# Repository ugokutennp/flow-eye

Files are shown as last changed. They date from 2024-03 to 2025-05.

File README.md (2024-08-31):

# flow-eye
IR Illuminator and Camera Mount for Valve Index DIY Eye Tracker

## Prototype
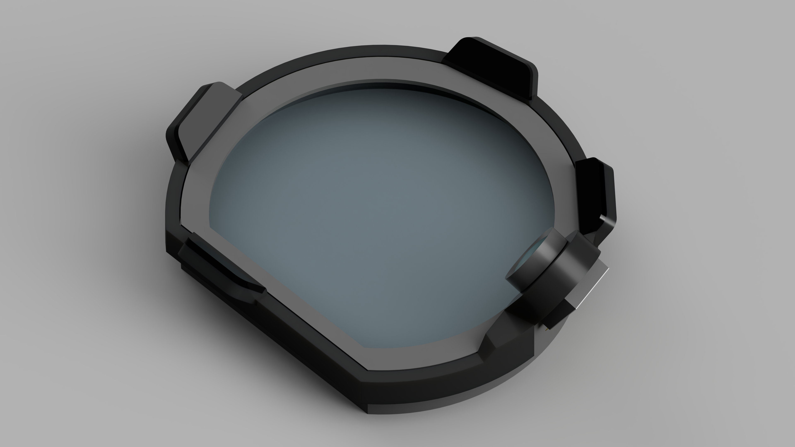
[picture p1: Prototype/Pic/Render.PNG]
Render

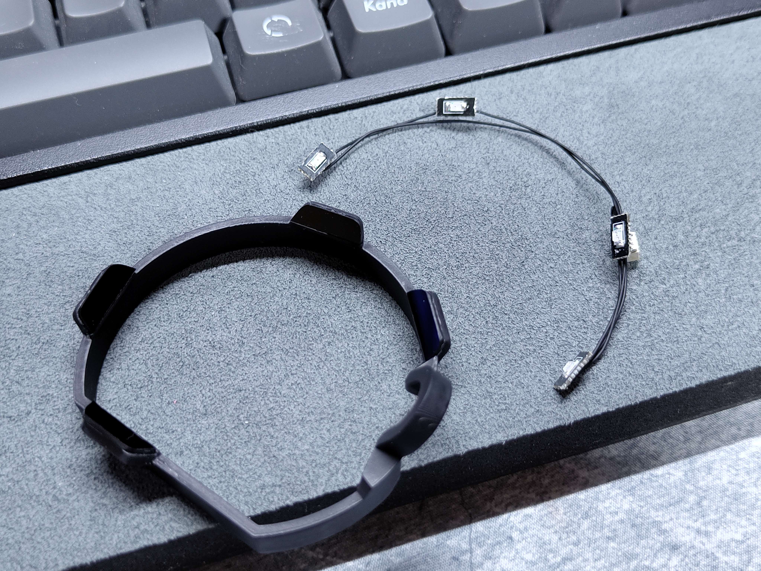
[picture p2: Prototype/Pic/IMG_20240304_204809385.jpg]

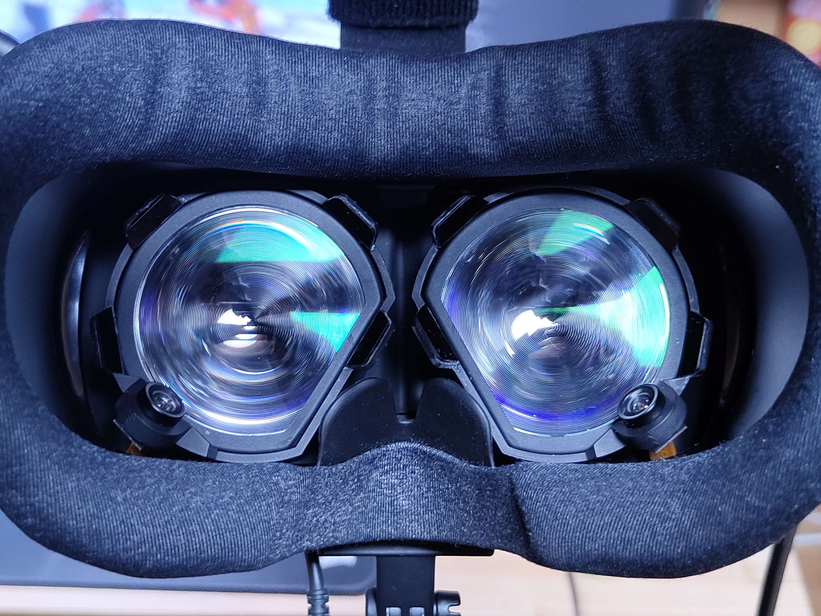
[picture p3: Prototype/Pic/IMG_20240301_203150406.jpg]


### Note
 - Designed for OV2640-160°.
 - A rubber ring is used to mount the camera.
 - The part in front of the LED is a visible light filter (acrylic that passes only infrared light). It is attached for appearance.

## Rev1.1
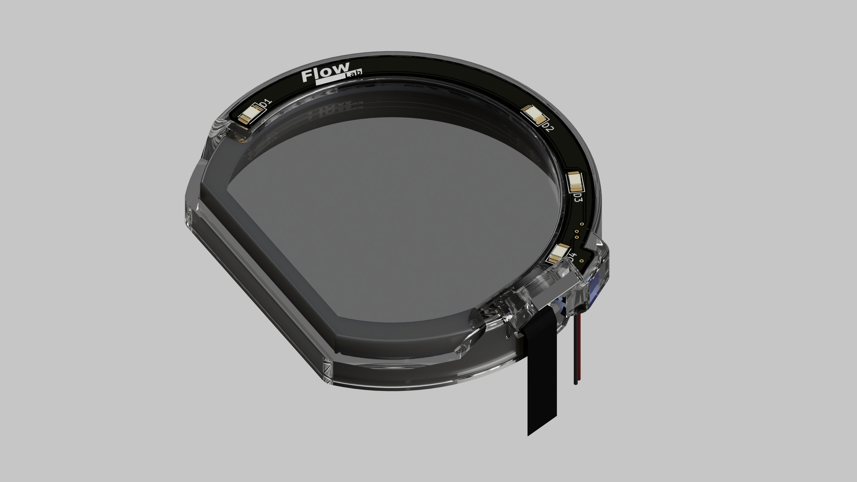
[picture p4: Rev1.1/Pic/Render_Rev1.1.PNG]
Render

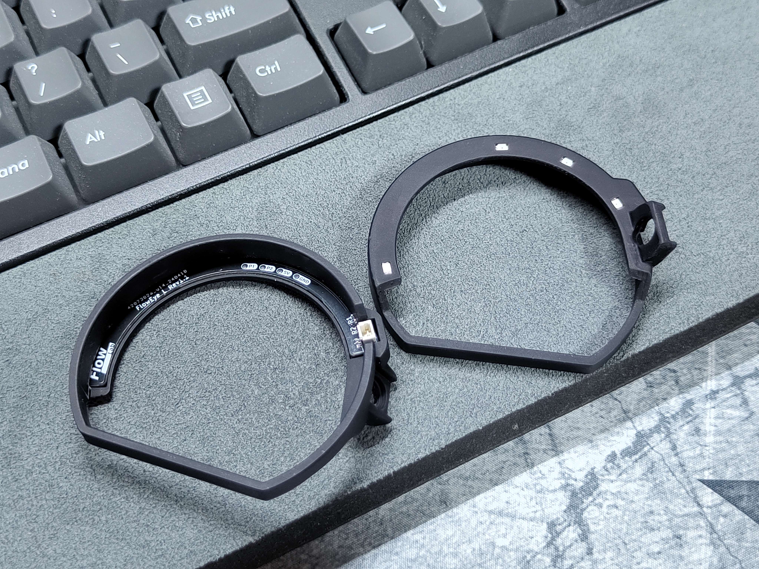
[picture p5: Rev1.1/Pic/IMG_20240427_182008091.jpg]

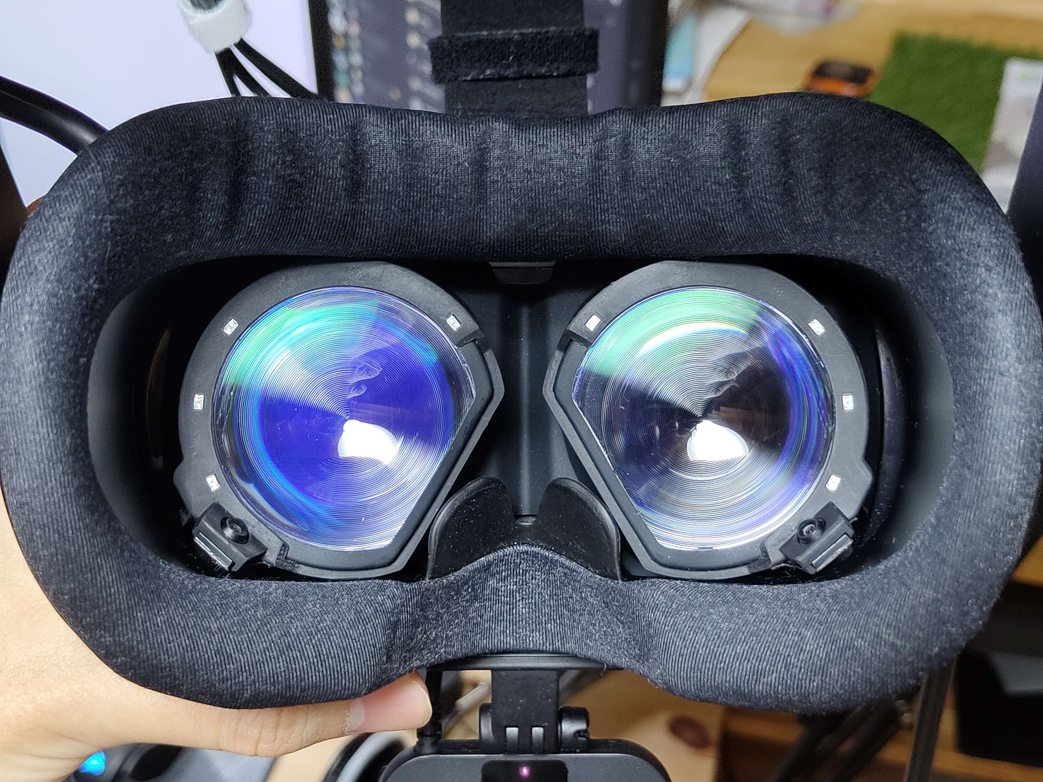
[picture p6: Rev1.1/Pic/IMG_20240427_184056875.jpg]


### Note
- Designed for OV2640-130°.
- Select a thickness of 0.8 mm when creating PCBs.
- [Schematic](https://github.com/ugokutennp/flow-eye/blob/main/Rev1.1/Pic/Schematic.png).
- [Other Notes (Japanese)](https://github.com/ugokutennp/flow-eye/blob/main/flow-eye.md).

## Frunk
3D data for the integration of a USB 3.0 2-port hub.
It was created based on the following data   
[Index Hardware](https://github.com/ValveSoftware/IndexHardware)

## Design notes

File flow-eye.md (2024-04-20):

# FlowEyeの使い方

## はじめに
FlowEyeはValve Index DIY アイトラッカー用のIRイルミネーターとカメラマウントのセットです。アイトラッカーとして動かすためにはいくつかの追加部品と作業が必要になります。基本的にはEyeTrackVRと互換性があるため、詳しい作業内容や必要部品については[公式ドキュメント](https://docs.eyetrackvr.dev/)をご覧ください。以下はFlowEyeを使う上での特記事項及び個人的な注意事項をまとめたものです。

## カメラの選定とIRフィルタの除去
FlowEyeは **OV2640-130°カメラモジュール** 向けに設計を行っています。
AliExpressでOV2640と検索し、130°レンズがついた物を購入してください。
また、130°レンズはIRフィルタ実装済みの商品しか出回っていないため、ご自身で[IRフィルタの除去](https://www.youtube.com/watch?v=QYH-FWvDbDc)を行っていただく必要があります。
※フィルタ直下にレンズがあるため、レンズを傷つけないよう十分注意して作業する必要があります(>_<)

## 赤外線LEDの安全性
FlowEyeはEyeTrackVR V3と同様に各LED(XL-3216HIRC-850)を **3.2[mA]** で駆動しています。安全性についての概算は[公式ドキュメント](https://docs.eyetrackvr.dev/getting_started/led_safety)をご覧ください。
また、実際の駆動電流を知りたい場合は裏面のテストポイントにおいて、5V-P1間及び5V-P2間の電位差を680[Ω]に対して十分に内部抵抗の大きい電圧計で計測し、2.2[V]程度であることを確認してください。   
$2.2[V]/680[Ω]=0.0032[A]$

## Flow Eyeへの給電
IRイルミネーターの駆動電圧は **5[V]** のため、USBのVBUSやESP32開発ボードの5V出力ピンで駆動させることができます。左右の電源は必ず並列に接続してください。

## USBハブの選定
有線モードのOpenIrisとVive Facial Trackerを同時に使用する場合、MTTのUSBハブを使用する必要があります。国内で安価かつ入手性の良いMTTのハブとして「Anker 4-Port Ultra-Slim USB 3.0 Hub」がお勧めです。

## BOM
|部品|必要個数|入手元|単価(円)|
|----|----:|----|----:|
|FlowEye|2|booth|1000|
|OV2640-130|2|AliExpress|750|
|Seeed Studio Xiao ESP32S3 Sense|2|AliExpress|2,000|
|Extra|
|FPCケーブル(24pin,0.5mm,25cm,A-Type)|2|AliExpress|150|
|FPC中継コネクタ(24pin,0.5mm)|2|AliExpress|20|
|Anker 4-Port Ultra-Slim USB 3.0 Hub|1|Amazon|1,300|
|Type-Cブレイクアウトボード|1|AliExpress|50|

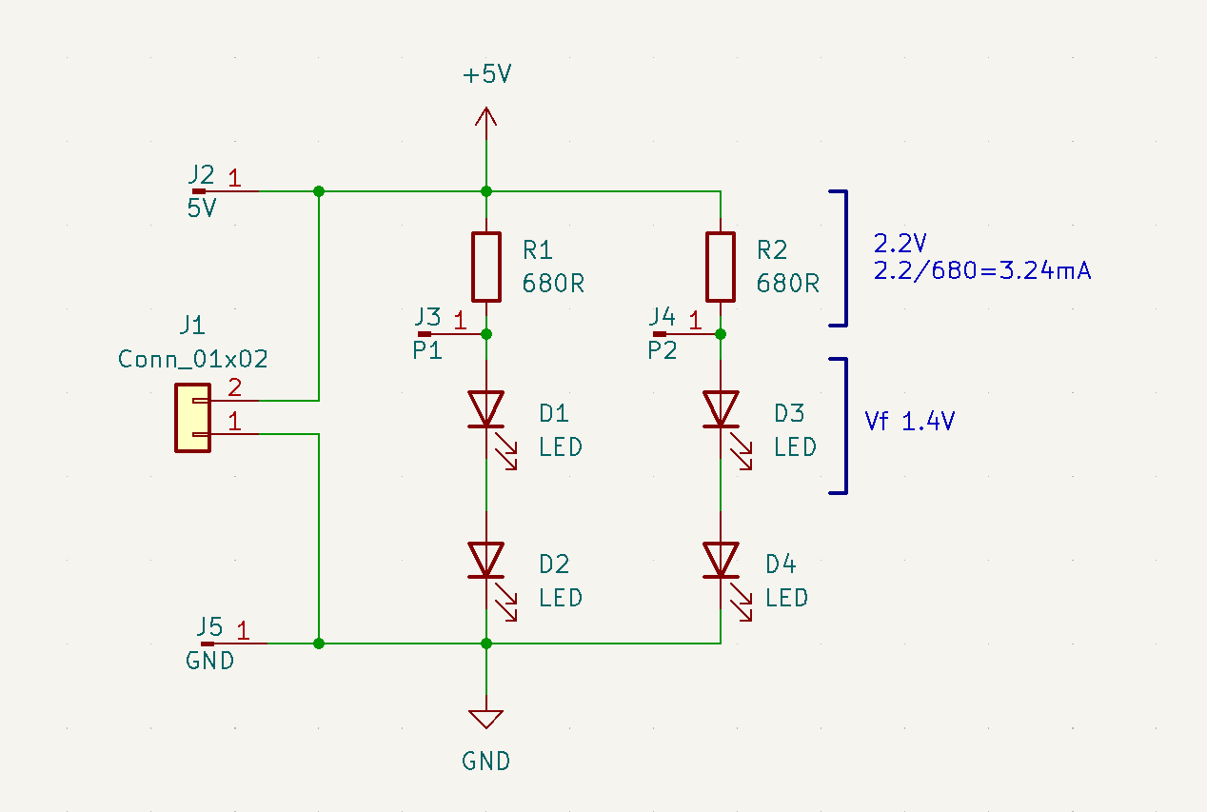
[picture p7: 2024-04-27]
Rev1.1/Pic/Schematic.png

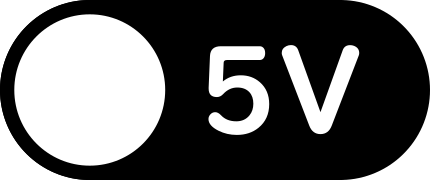
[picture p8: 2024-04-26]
Rev1.1/PCB/Silk/5V.png

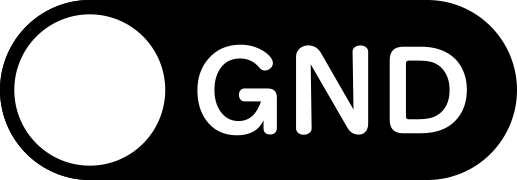
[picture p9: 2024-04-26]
Rev1.1/PCB/Silk/GND.png

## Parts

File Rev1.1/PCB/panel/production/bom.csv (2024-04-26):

Designator | Footprint | Quantity | Value | LCSC Part #
D1, D2, D3, D4 | 1206 | 4 | LED
J1 | JST_SH_BM02B-SRSS-TB_1x02-1MP_P1.00mm_Vertical | 1 | Conn_01x02
J2 | TestPoint_Pad_D1.0mm | 1 | Pad1
J3 | TestPoint_Pad_D1.0mm | 1 | Pad2
J4, J5 | TestPoint_Pad_D1.0mm | 2 | Pad3
R1, R2 | 0603 | 2 | 680R

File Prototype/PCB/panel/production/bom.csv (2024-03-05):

Designator | Footprint | Quantity | Value | LCSC Part #
D1_24, D1_23, D1_22, D1_21, D1_20, D1_19, D1_18, D1_17, D1_16, D1_15, D1_14, D1_13, D1_12, D1_11, D1_10, D1_9, D1_8, D1_7, D1_6, D1_5, D1_4, D1_3, D1_2, D1 | 1206 | 24 | LED
R1_24, R1_23, R1_22, R1_21, R1_20, R1_19, R1_18, R1_17, R1_16, R1_15, R1_14, R1_13, R1_12, R1_11, R1_10, R1_9, R1_8, R1_7, R1_6, R1_5, R1_4, R1_3, R1_2, R1 | 0603 | 24 | R
R2_24, R2_23, R2_22, R2_21, R2_20, R2_19, R2_18, R2_17, R2_16, R2_15, R2_14, R2_13, R2_12, R2_11, R2_10, R2_9, R2_8, R2_7, R2_6, R2_5, R2_4, R2_3, R2_2, R2 | 2816 | 24 | R

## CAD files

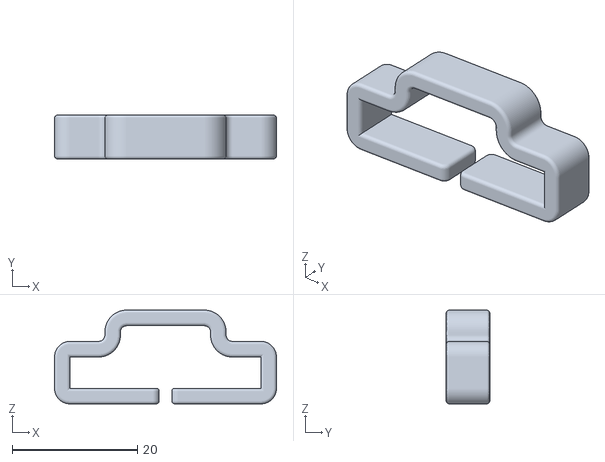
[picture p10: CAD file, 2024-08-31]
Frunk/clip.stl
35.5 x 7.00 x 15.0

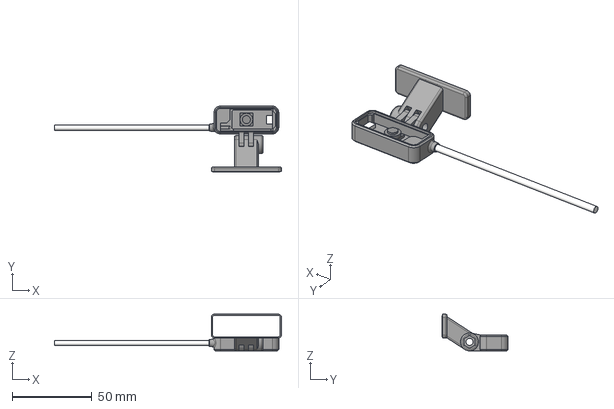
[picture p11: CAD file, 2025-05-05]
Lip/flowlip.step
142.3 x 41.3 x 23.0 mm

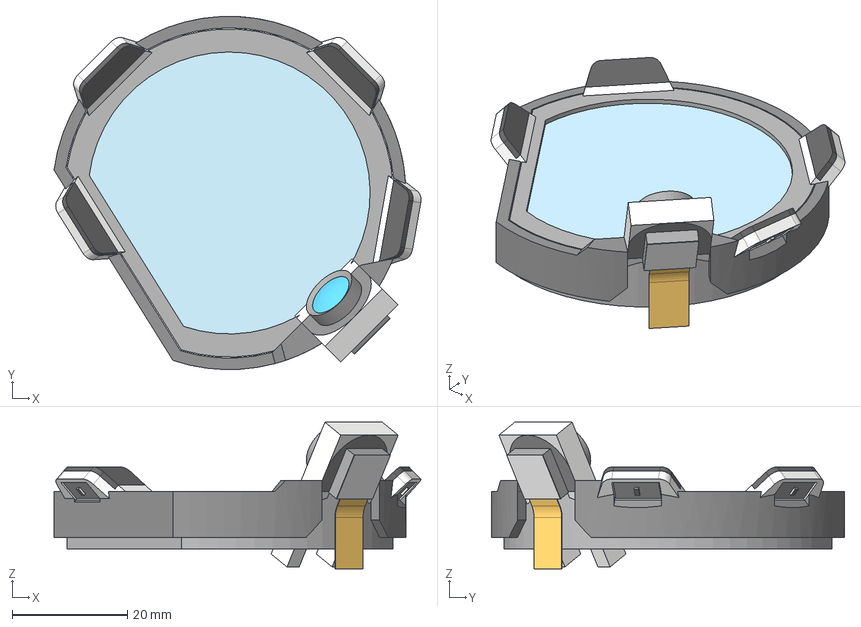
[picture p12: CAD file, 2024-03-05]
Prototype/Mount/FlowEye_Proto.step
63.8 x 61.4 x 25.5 mm
OV2640
Pcb_bffd x 4
PCB_Sketch_bffd x 4
D1_LED_1206_3216Metric_4e3c16dcd79f x 4
R1_R_0603_1608Metric_49bde42c65aa x 4

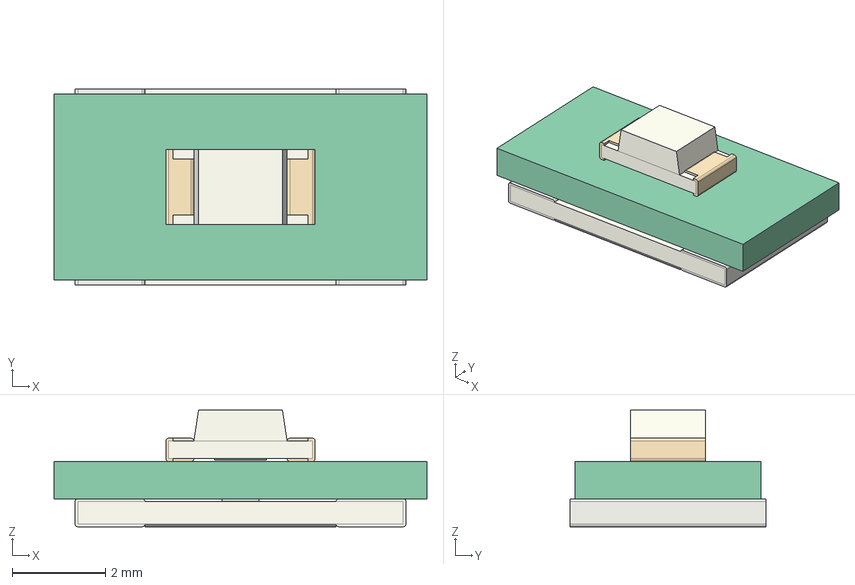
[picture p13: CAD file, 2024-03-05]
Prototype/PCB/FlowLight.step
8.00 x 4.20 x 2.50 mm
Local_CS_bffd x 2
Pcb_bffd x 3
PCB_Sketch_bffd x 3
D1_LED_1206_3216Metric_4e3c16dcd79f x 4
R1_R_0603_1608Metric_49bde42c65aa x 3
R2_R_2816_7142Metric_79183b92b078 x 3

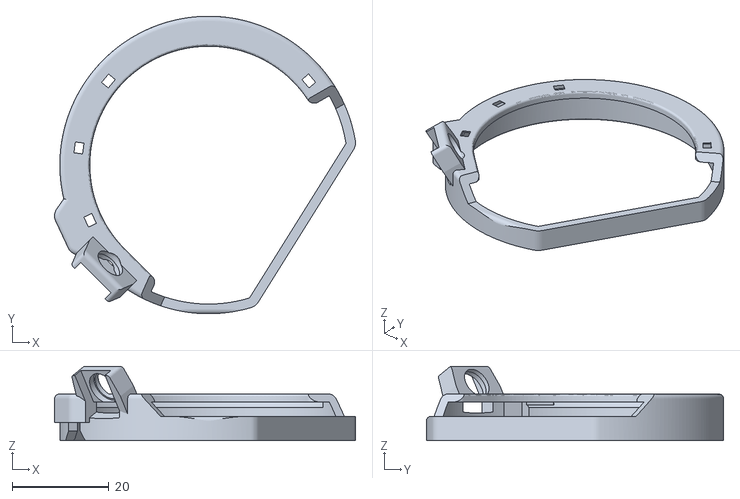
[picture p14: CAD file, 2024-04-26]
Rev1.1/Mount/FlowEye_Rev1.1_L.stl
62.1 x 61.4 x 15.3

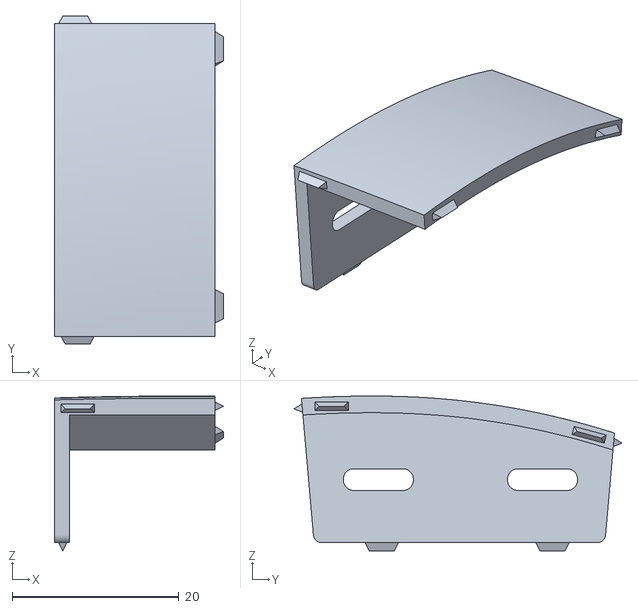
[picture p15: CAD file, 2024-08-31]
Frunk/cover.stl
20.3 x 39.4 x 18.6

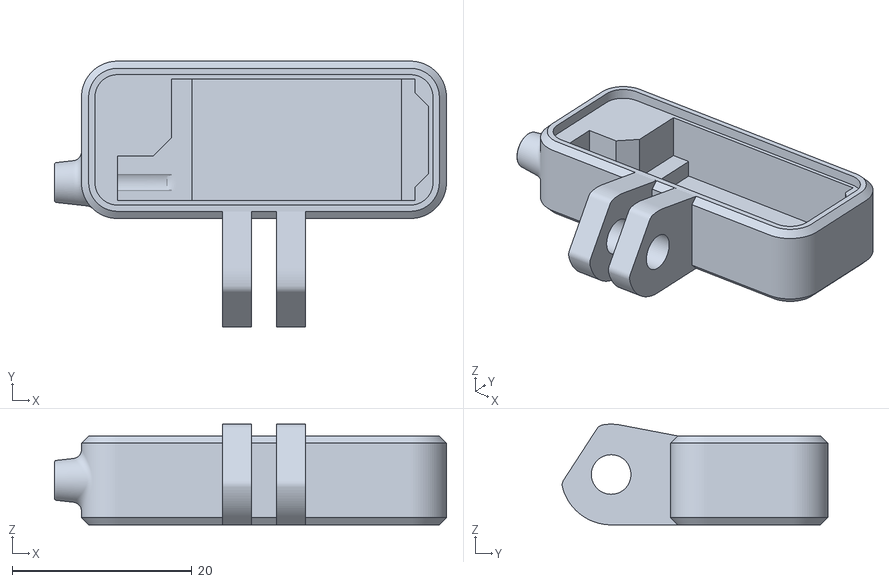
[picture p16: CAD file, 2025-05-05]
Lip/enclosure.stl
43.6 x 29.6 x 11.2

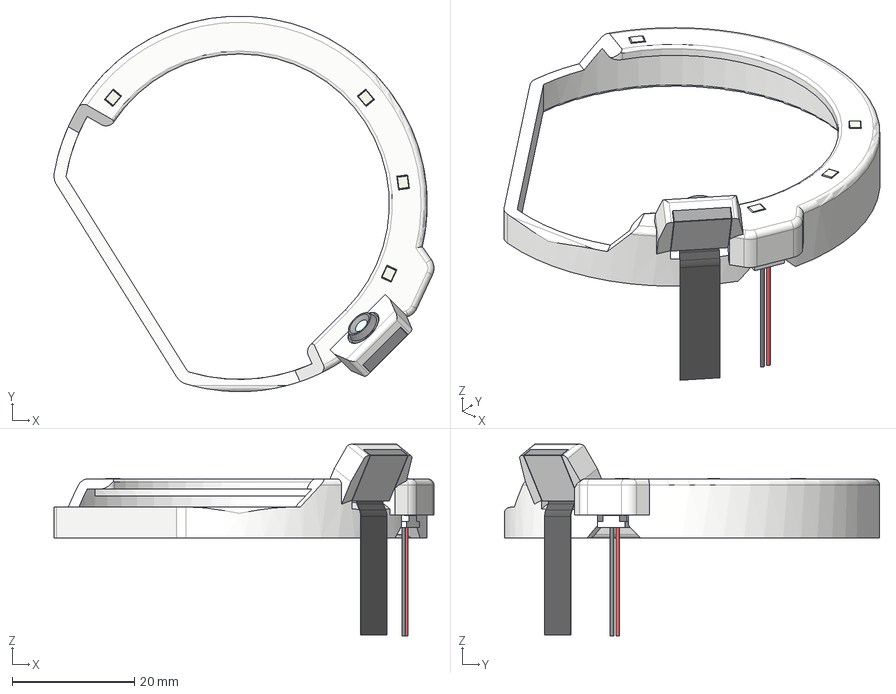
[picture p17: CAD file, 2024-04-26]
Rev1.1/Mount/FlowEye_Rev1.1.step
62.1 x 61.4 x 31.3 mm
OV2640_130
SHR-02V-S-B
Pcb_4213
topPads_4213
topTracks_4213
topZones_4213
botPads_4213
botTracks_4213
botZones_4213
botSilks_1697
topSilks_1b43
D2_LED_1206_3216Metric_46bda04861c9 x 4
R1_R_0603_1608Metric_dd5ba7a799db x 2
J1_BM02B-SRSS_8741ff7fa410[2]

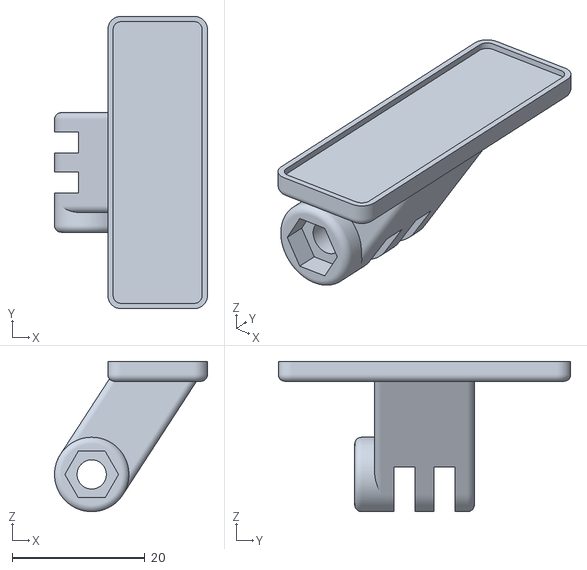
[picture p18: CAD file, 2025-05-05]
Lip/mount.stl
23.0 x 44.0 x 22.6

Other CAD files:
Rev1.1/Mount/FlowEye_Rev1.1_R.stl
Prototype/Mount/FlowEye_Proto.stl

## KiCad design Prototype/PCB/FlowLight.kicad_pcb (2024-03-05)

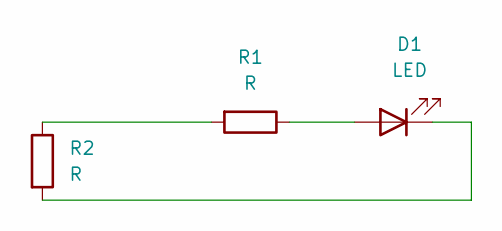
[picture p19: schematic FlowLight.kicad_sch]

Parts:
D1: LED; LED_1206_3216Metric_Pad1.42x1.75mm_HandSolder
R1: R; R_0603_1608Metric
R2: R; R_2816_7142Metric

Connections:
unnamed: D1.1 (K), R2.2
unnamed: D1.2 (A), R1.1
unnamed: R1.2, R2.1

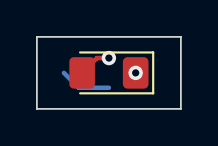
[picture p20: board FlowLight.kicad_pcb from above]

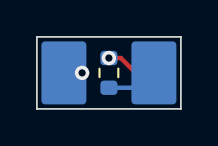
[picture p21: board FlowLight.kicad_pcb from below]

Board: 2 copper layers, 8.0 x 4.0 mm, 3 parts (2 on the bottom side), 3 nets.

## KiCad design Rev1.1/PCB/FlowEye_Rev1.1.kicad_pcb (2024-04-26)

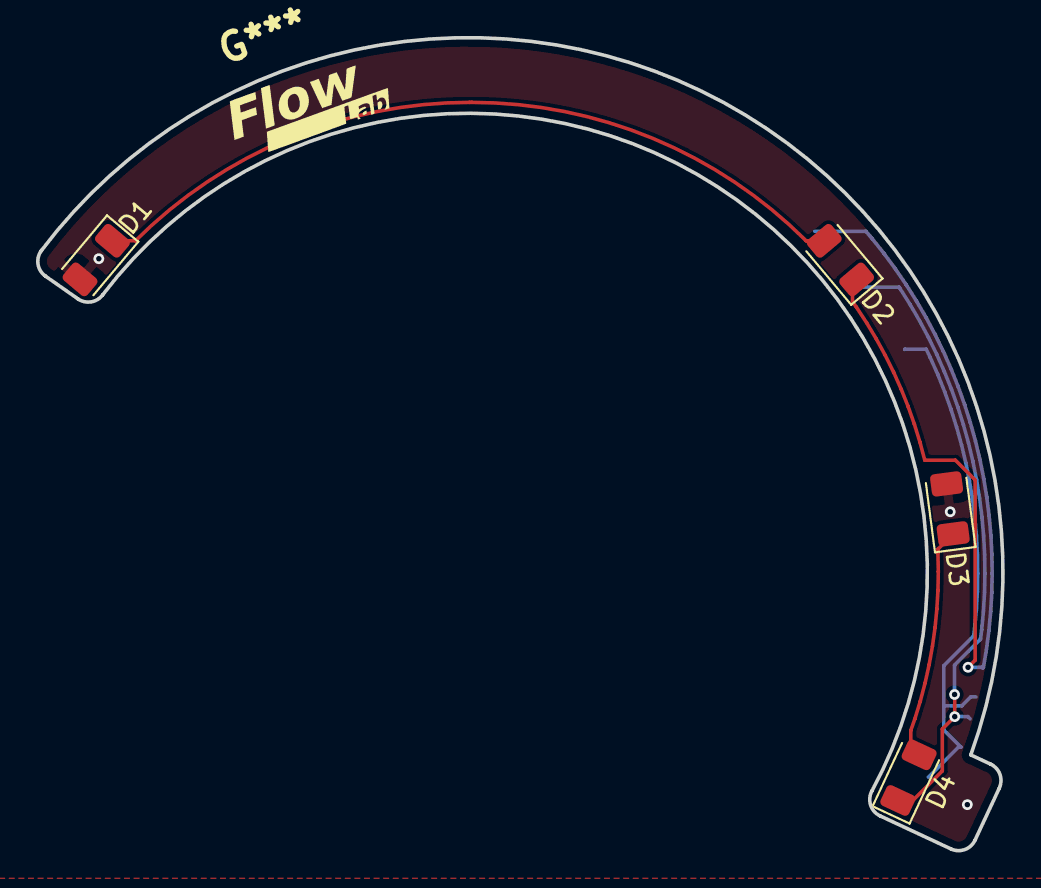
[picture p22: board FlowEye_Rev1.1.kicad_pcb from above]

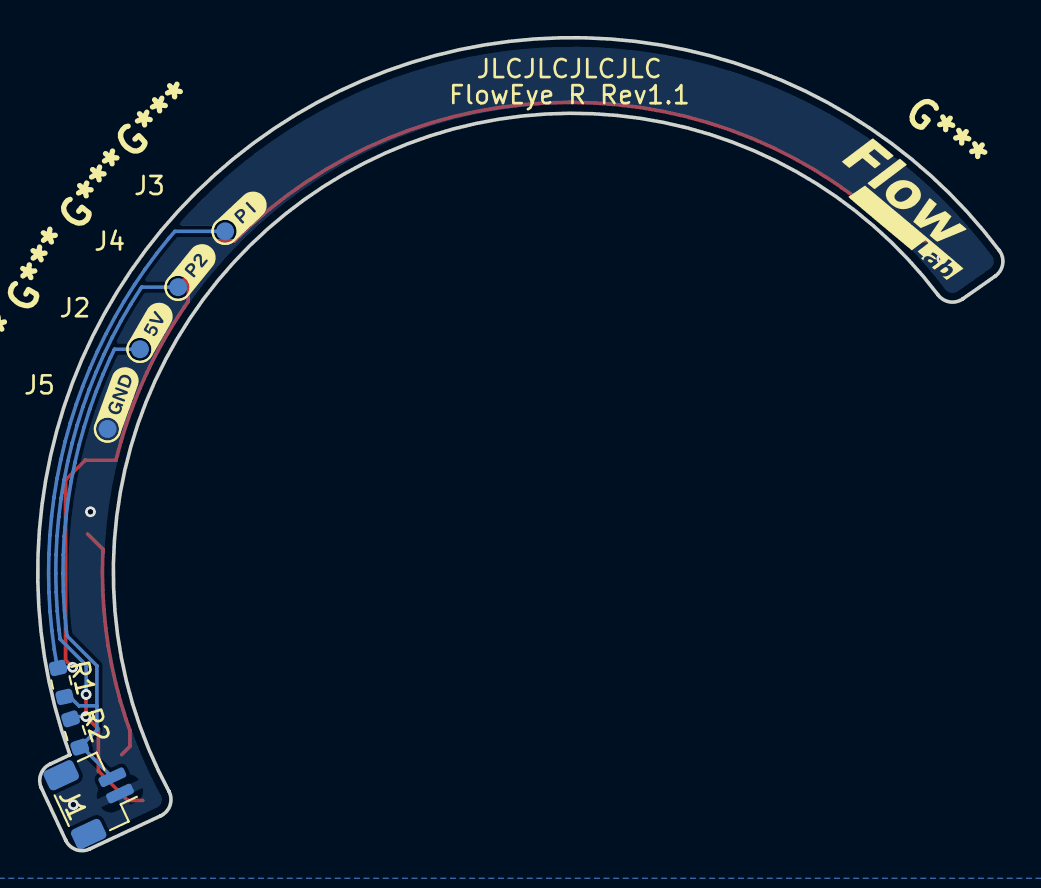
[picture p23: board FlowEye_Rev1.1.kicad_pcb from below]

Board: 2 copper layers, 53.6 x 45.2 mm, 11 parts (7 on the bottom side), 6 nets.

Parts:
D1, D2, D3, D4: LED; LED_1206_3216Metric
J1: Conn_01x02; JST_SH_BM02B-SRSS-TB_1x02-1MP_P1.00mm_Vertical
J2: Pad1; TestPoint_Pad_D1.0mm
J3: Pad2; TestPoint_Pad_D1.0mm
J4, J5: Pad3; TestPoint_Pad_D1.0mm
R1, R2: 680R; R_0603_1608Metric

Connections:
+5V: J1.2, J2.1, R1.1, R2.1
GND: D1.2 (A), D3.2 (A), J1.1, J5.1
unnamed: D2.1 (K), J3.1, R1.2
unnamed: D1.1 (K), D2.2 (A)
unnamed: D4.1 (K), J4.1, R2.2
unnamed: D3.1 (K), D4.2 (A)

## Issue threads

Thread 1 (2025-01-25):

Widmovr lenses adapter

tompointexe, 2025-01-25:
Hey, awsome PCB, from your pics it looks like an OEM addon !

I use WidmoVR Prescription lenses, is there any way you could help me make an edit of your REV1.1 PCB and model to be able to fit it over the lenses ?
here is a public 3D model that replicates the ones i have (i have tested it personaly as their print always break every year or so :( ) https://github.com/Lerx-cnm/WidmovrIndexInsert/tree/master

Thanks a lot !

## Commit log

2024-03-05 Upload Prototype data
    [FlowEye_Proto.step, FlowEye_Proto.stl, FlowLight.kicad_pcb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]
2024-04-26 Add Rev1.1
    [FlowEye.kicad_sch, FlowEye_Rev1.1.kicad_pcb, FlowEye_Rev1.1.step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]
2024-08-31 Add Frunk
    [cover.stl]
2024-08-31 Add clinp
    [clip.stl]
